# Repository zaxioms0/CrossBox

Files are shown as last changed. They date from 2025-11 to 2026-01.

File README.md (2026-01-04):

# CrossBox
A printer for the NYT mini crossword

Thanks for visiting! [People on Reddit](https://www.reddit.com/r/crossword/comments/1oy7tg7/i_made_a_box_to_print_the_nyt_mini/) 
seemed to think this was cool, so I'm putting it on Github if anyone
else wants to make it. ~~This currently *does* work without an NYT Games subscription. Hopefully it stays that way :]~~ 
In order to use the NYT mini, you need to provide an NYT-S token which is availible to anyone with an NYT Games subscription. 
The boxes also can print the [Puzzmo Mini](https://www.puzzmo.com/today/)
if you do not have an NYT Games subscription. If you are interested in building this project for yourself,
I highly recommend using the version for the ESP32 as well as v3 of the box. 

The current version is in the `esp32` directory and all development going forward will be for it. Due to the changes to the NYT API 
and the lack of development, the `esp8266` version does not work and also will not be updated.

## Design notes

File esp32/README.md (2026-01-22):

# Usage Instructions
## Startup
When the box is plugged in, it will try to connect to the internet. If it succeeds, it will blink 3 times quickly. If it fails,
it will open up a WiFi network for configuring settings. Sometimes it will connect to the internet, but fail to obtain the time.
I think this is due to NTP server rate limiting. If this happens it will print an error message before restarting and trying again.

## Main Usage
- Press and release button: print the selected mini crossword.
- Press and hold button for 5 seconds: open up WiFi network for configuration settings.

## WiFi Configuration
During WiFi Configuration, the button will blink slowly. If it is blinking, it means there is a WiFi network called
`CrossBox Setup` that you can connect to. Once connected, it should open a captive portal automatically on modern devices (like airplane WiFi), but it can
also be accessed through any browser at IP Address `192.168.4.1`. In this menu you can:
- Set the WiFi network and password
- Add/Change the NYT-S token (see section)
- Set a time for automatic printing
- Switch between the NYT Mini and Puzzmo Mini

Settings which are left empty will not be updated. The box will not return to it's normal state until the settings
are saved (or it loses and regains power).

### NYT-S Token
In order to use the NYT mini, you need to provide an NYT-S cookie. You can aquire it by inspecting element 
on the NYT Mini site, going to storage, then cookies. And there should be an NYT-S cookie which is a base-64 string.
Make sure you just provide the string without any quotes or "NYT-S" prepended to it.

# Assembly
## Parts Required 
- [ESP32](https://www.amazon.com/dp/B0D8T53CQ5?ref=ppx_yo2ov_dt_b_fed_asin_title).
- [Thermal Printer](https://www.amazon.com/dp/B09YGVPPWV).
- [Buck Converter](https://www.amazon.com/UCTRONICS-Converter-Transformer-Voltage-Regulator/dp/B07XXWQ49N).
- [Arcade Button](https://www.amazon.com/dp/B07XYV5NNP)
- Power Supply. I used 9v 3a. Anything more than 5v 3a should be sufficient.
- 6mm diameter x 1 mm width magnets (for box v3).
- Misc. Wires

## Wiring Directions
All you need is one power rail and one ground rail wired in a clear manner, positive out of the buck converter to one, 
ground of the buck converter to the other. The power wires of the printer are connected to these rails as well as the VIN
pin of the ESP32 to power and its ground to the ground rail. The wires that depend on specific pins are configured as follows:

- Printer TX to GPIO 25.
- Printer RX to GPIO 26.
- One button press terminal to GPIO 19.
- Other button press terminal to ground (ESP32 pin or rail).
- Button positive LED to GPIO 18.
- Button negative LED to GPIO 5.

If you are using the parts linked above, physical descriptions of the relevant wires/terminals are in [globals.h](src/globals.h).

## Software Directions
I used PlatformIO for all of the library handling. The only important note is you need to change the Baud rate to 9600
on line 38 of Adafruit_Thermal.cpp when it is downloaded.

The `ALI_EXPRESS` flag in `globals.h` should be set to `0` for the version of the printer I linked above.
This is used for a model which doesn't have as good defaults and has some settings that need to be set manually.

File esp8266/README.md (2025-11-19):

# Parts
Here is a list of parts I used (not including wires and stuff)

I included Amazon Links to the exact models of some of the parts that I used. You can probably get them
for cheaper on Ali Express or similar - I am fortunate to have a robotics club that stocks these for me :]

- 12v to 5v buck converter
- Breadboard
- 12v 3a power supply
- [58mm thermal printer](https://www.amazon.com/Maikrt-Embedded-Microcontroller-Secondary-Development/dp/B09YGVPPWV)
- [WEMOS D1 Mini](https://www.amazon.com/Hosyond-Wireless-Internet-Development-Compatible/dp/B09SPYY61L)

# Setup
## Software
I use PlatformIO to handle dependencies. The only thing in software that needs to be changed are your
wifi SSID and password, and ROOT CA certificate in `src/creds.h`.

The way it works is that a button resets the microcontroller and it reconnects to the internet.
To be honest this is not a great design because it takes a long time to connect to the internet every time.
I did this because I have no idea how the JSON parser is allocating memory and I'm worried about using too much
if it leaks or something. I want to improve this in the future.

## Hardware
Besides 3D printing the models, the wiring is fairly straightforward. 
Here are the connections neccesary:
- Buck Converter -> Breadboard: positive goes to positive, negative to negative
- Breadboard Power Rails -> D1 Mini: Positive to 5v, negative to ground
- Printer Power -> Power Rails: positive to positive, negative to negative
- Printer TTL -> Breadboard: ground to ground, RX to GPIO 16, TX to GPIO 14
- Big Button -> Breadboard: positive to reset, negative to ground

Your power supply should supply 12v into the buck converter and at least 3 amps. 
If you have a power supply with 5 volts and 3 (or more) amps, the buck converter can be skipped.

# Disclaimer
I am fairly new to this whole electronics thing, lots of things can (and probably will) be improved.
In particular, I want to handle JSON parsing without a library for space reasons. 
Also, the box design right now is too tight, I plan to change it to use magnets for the connection in v3.

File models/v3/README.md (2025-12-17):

# Materials
Version 3 of the box requires 8 magnets with a diameter of 6mm and a depth of 1mm.

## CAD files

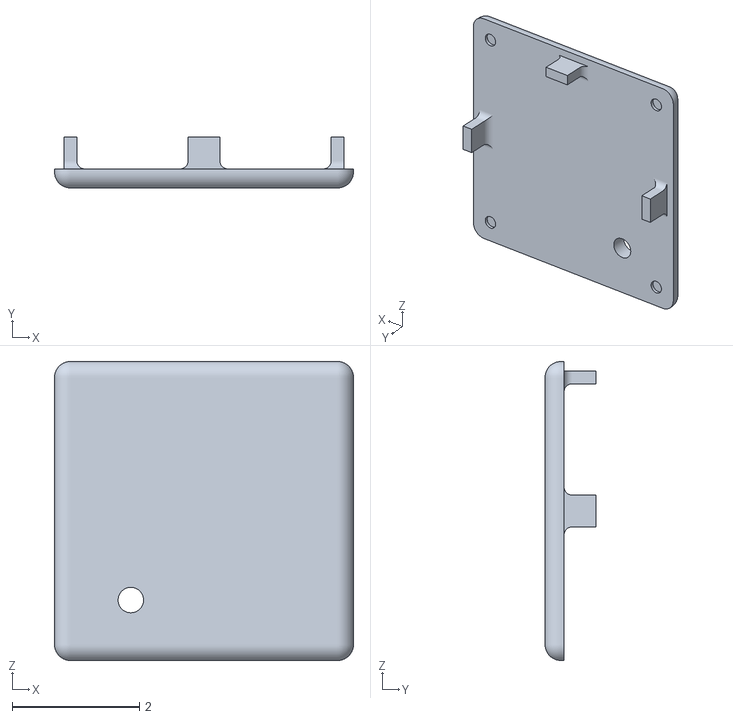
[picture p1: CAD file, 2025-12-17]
models/v3/back.stl
4.70 x 0.8 x 4.70

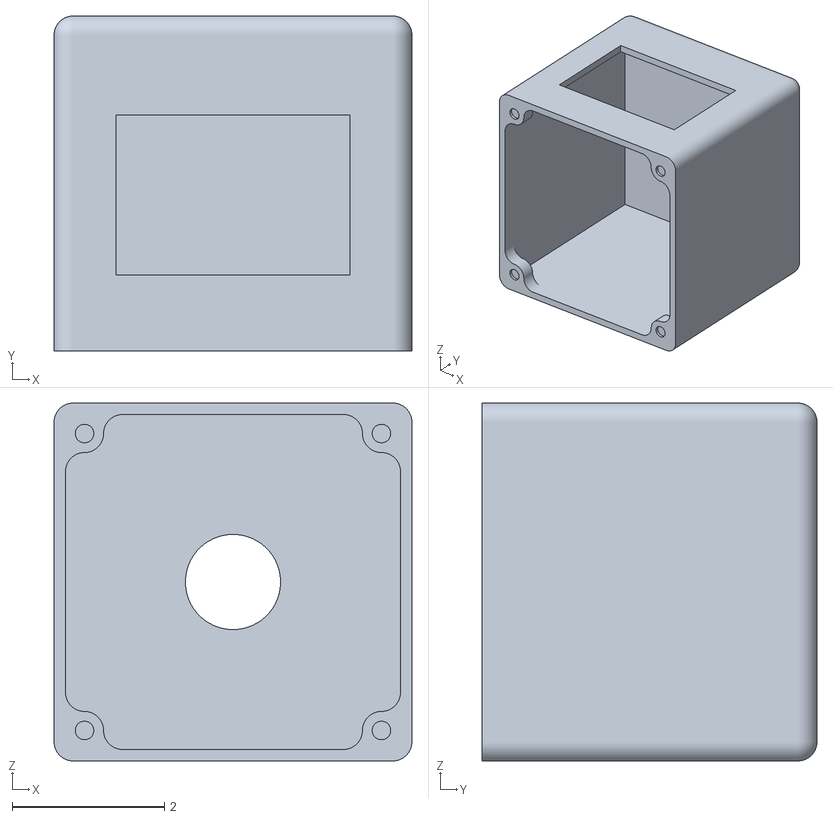
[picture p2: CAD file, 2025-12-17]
models/v3/box.stl
4.70 x 4.40 x 4.70

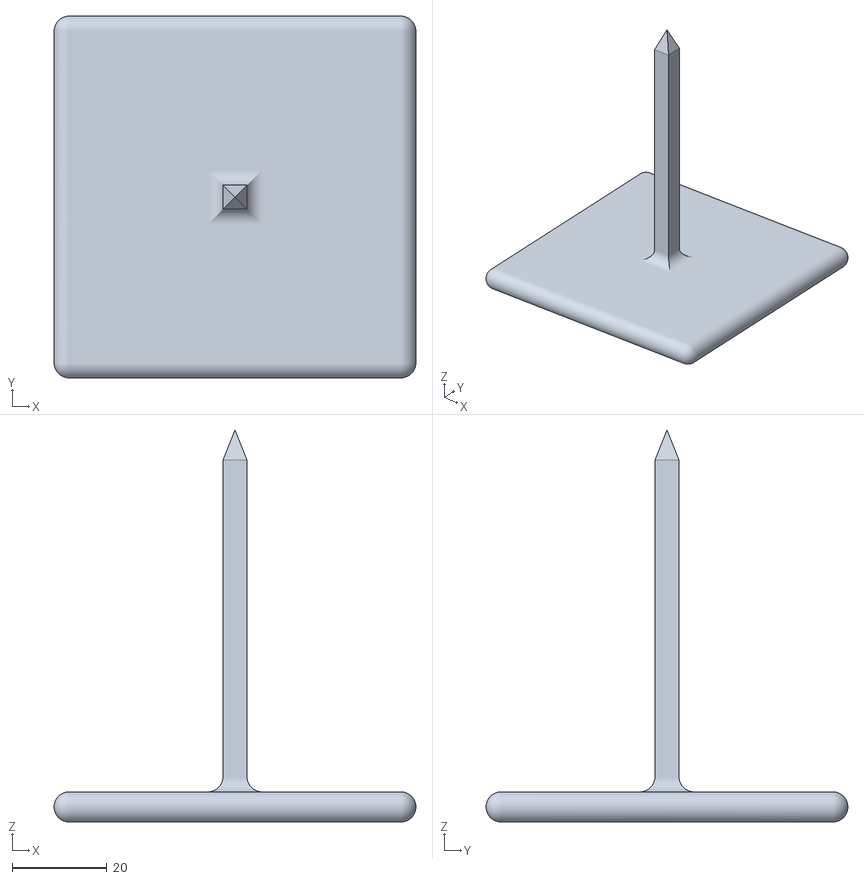
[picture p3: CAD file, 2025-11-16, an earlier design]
models/v2/spike.stl
76.2 x 76.2 x 82.5

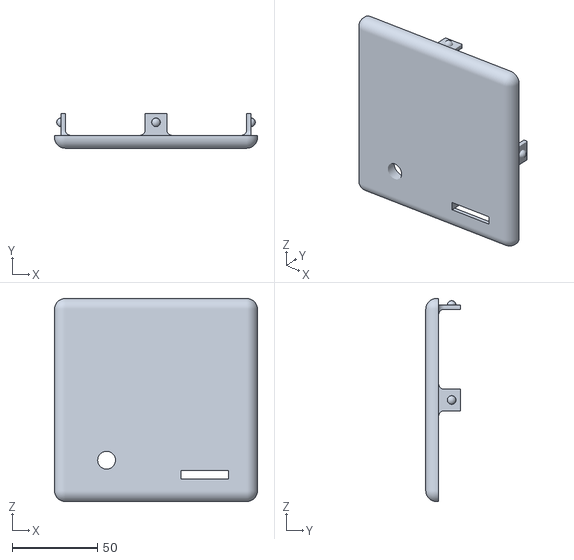
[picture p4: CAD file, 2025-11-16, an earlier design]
models/v2/back.stl
119.4 x 20.3 x 119.4

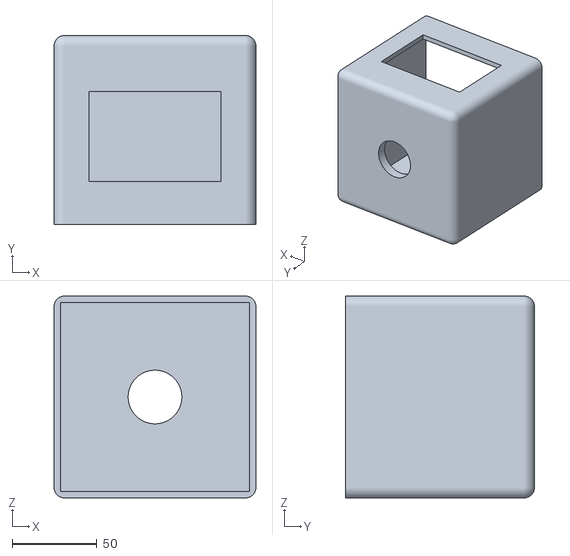
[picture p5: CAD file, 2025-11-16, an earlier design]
models/v2/box.stl
119.4 x 111.8 x 119.4

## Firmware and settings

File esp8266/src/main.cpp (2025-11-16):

#include "SoftwareSerial.h"
#include <Adafruit_Thermal.h>
#include <Arduino.h>
#include <ArduinoJson.h>
#include <ESP8266HTTPClient.h>
#include <ESP8266WiFi.h>
#include <WiFiClientSecure.h>
#include <creds.h>
#include <nums.h>
#include <time.h>
#include <vector>

// RX, TX
SoftwareSerial printer_serial(14, 16);
Adafruit_Thermal printer(&printer_serial);
int board_px = 384;
const int scratch_size = 4400;
char scratch[scratch_size] = "{\"cells\":";

struct GridData {
    int height;
    int width;
    std::vector<String> authors;
    // ((x, y), data)
    std::vector<std::pair<std::pair<int, int>, int>> square_data;
    std::vector<std::pair<int, String>> across_clues;
    std::vector<std::pair<int, String>> down_clues;
};

void printGridData(GridData d) {
    Serial.printf("Height: %d\n", d.height);
    Serial.printf("Width: %d\n", d.width);
    Serial.print("Author(s): ");
    for (size_t i = 0; i < d.authors.size(); i++) {
        Serial.print(d.authors[i].c_str());
        if (i < d.authors.size() - 1)
            Serial.print(", ");
    }
    Serial.println();
    Serial.print("Data: ");
    for (auto p : d.square_data) {
        Serial.printf("<(%d, %d) : %d> ", p.first.first, p.first.second,
                      p.second);
    }
    Serial.println();
    Serial.println("Across:");
    for (auto p : d.across_clues) {
        Serial.printf("%d: %s\n", p.first, p.second.c_str());
    }
    Serial.println();
    Serial.println("Down:");
    for (auto p : d.down_clues) {
        Serial.printf("%d: %s\n", p.first, p.second.c_str());
    }
}

void getDateString(char *buff, bool pp) {
    struct tm timeinfo;
    if (!getLocalTime(&timeinfo)) {
        Serial.println("Failed to obtain time");
        exit(1);
    }
    if (pp)
        sprintf(buff, "%d/%d/%d", 1 + timeinfo.tm_mon, timeinfo.tm_mday,
                1900 + timeinfo.tm_year);
    else
        sprintf(buff, "%d-%d-%d", 1900 + timeinfo.tm_year, 1 + timeinfo.tm_mon,
                timeinfo.tm_mday);
}

// returns index of null terminator in buff
int readStreamUntil(WiFiClient *stream, const char *match, int match_len,
                    char *buffer, int buffer_len) {
    int i = 0;
    int idx = 0;
    while ((stream->connected() || stream->available()) && i < match_len &&
           (!buffer || (idx < buffer_len))) {
        if (stream->available()) {
            char c = stream->read();
            if (c == match[i]) {
                i += 1;
            } else {
                i = 0;
            }
            if (buffer != NULL) {
                buffer[idx] = c;
            }
            idx += 1;
        } else {
            yield();
        }
    }
    if (buffer != NULL)
        buffer[idx] = 0;
    return idx;
}

GridData getGridData() {
    char url[128];
    char date[64];
    WiFiClientSecure client;
    HTTPClient http;
    getDateString(date, false);
    sprintf(url,
            "https://www.nytimes.com/svc/crosswords/v6/puzzle/mini/%s.json",
            date);
    Serial.println(url);

    http.setFollowRedirects(HTTPC_STRICT_FOLLOW_REDIRECTS);
    client.setTrustAnchors(new X509List(root_ca));
    http.begin(client, url);

    delay(1000);
    int httpResponseCode = http.GET();
    if (httpResponseCode == 403) {
        // try again with tomorrow's date
        configTime((24 - 4) * 60 * 60, 0, "time.google.com");
        getDateString(date, false);
        sprintf(url,
                "https://www.nytimes.com/svc/crosswords/v6/puzzle/mini/%s.json",
                date);
        http.begin(client, url);
        delay(1000);
        httpResponseCode = http.GET();
    }

    if (httpResponseCode != 200) {
        Serial.printf("Failed to get NYT data. HTTP response: %d\n",
                      httpResponseCode);
        exit(1);
    }

    auto s = http.getStreamPtr();
    JsonDocument doc;
    bool succeeded = false;
    {
        for (int i = 0; i < 3; i++) {
            const char start_target[9] = "\"cells\":";
            const char end_target[4] = "SVG";

            readStreamUntil(s, start_target, 8, NULL, 0);
            int buf_len =
                readStreamUntil(s, end_target, 3, scratch + 9, scratch_size);
            scratch[9 + buf_len - 5] = '}';
            scratch[9 + buf_len - 4] = 0;
            DeserializationError error = deserializeJson(doc, scratch);
            if (error) {
                Serial.println("JSON parsing failed: ");
                Serial.println(error.c_str());
                Serial.print(scratch);
                http.GET();
                s = http.getStreamPtr();
            } else {
                succeeded = true;
                break;
            }
        }
    }
    if (!succeeded) {
        Serial.println("Didn't work. Sorry :(");
        exit(1);
    }
    // serializeJsonPretty(doc, Serial);
    GridData data;
    data.height = doc["dimensions"]["height"].as<int>();
    data.width = doc["dimensions"]["width"].as<int>();
    data.square_data = {};
    data.authors = {};
    data.across_clues = {};
    data.down_clues = {};
    for (int j = 0; j < data.height; j++) {
        for (int i = 0; i < data.width; i++) {
            int idx = i + data.width * j;
            if (doc["cells"][idx] &&
                doc["cells"][idx].as<JsonObject>().size() == 0) {
                data.square_data.push_back({{i, j}, 0});
            } else if (doc["cells"][idx]["label"]) {
                int label =
                    atoi(doc["cells"][idx]["label"].as<String>().c_str());
                data.square_data.push_back({{i, j}, label});
            }
        }
    }
    for (auto clue : doc["clues"].as<JsonArray>()) {
        String direction = clue["direction"].as<String>();
        int label = atoi(clue["label"].as<String>().c_str());
        String text = clue["text"][0]["plain"].as<String>();
        if (strcmp(direction.c_str(), "Across") == 0) {
            data.across_clues.push_back({label, text});
        } else {
            data.down_clues.push_back({label, text});
        }
    }
    doc.clear();
    const char start_target[16] = "\"constructors\":";
    const char end_target[12] = "\"copyright\"";
    readStreamUntil(s, start_target, 15, NULL, 0);
    strcpy(scratch, "{\"constructors\":");
    int buflen = readStreamUntil(s, end_target, 11, scratch + 16, scratch_size);
    scratch[16 + buflen - 12] = '}';
    scratch[16 + buflen - 11] = 0;
    Serial.printf("%d, %s\n", buflen, scratch);
    Serial.flush();
    DeserializationError error = deserializeJson(doc, scratch);
    if (error) {
        Serial.println("JSON parsing constructors failed: ");
        Serial.println(error.c_str());
        exit(1);
    }
    for (auto author : doc["constructors"].as<JsonArray>()) {
        String a = author.as<String>();
        data.authors.push_back(a);
    }

    printGridData(data);
    digitalWrite(2, HIGH);

    return data;
}

void writeScratchBit(int i) {
    int b = i / 8;
    int offset = 7 - (i % 8);
    scratch[b] |= ((char)1) << offset;
}

void writeOutline(int square_dim, int width) {
    for (int x = 0; x < width; x++) {
        for (int i = 0; i < square_dim; i++) {
            // top
            writeScratchBit(x * square_dim + i);
            writeScratchBit(x * square_dim + board_px + i);
            // left
            writeScratchBit(x * square_dim + (board_px * i));
            writeScratchBit(x * (square_dim) + (board_px * i) + 1);
            // bottom
            writeScratchBit(x * square_dim + (board_px * (square_dim - 2)) + i);
            writeScratchBit(x * square_dim + (board_px * (square_dim - 1)) + i);
        }
    }
    // right
    for (int i = 0; i < square_dim; i++) {
        writeScratchBit(i * board_px + (board_px - 1));
        writeScratchBit(i * board_px + (board_px - 2));
    }
}

void writeSquare(int col, int square_dim, int data) {
    // fill in
    if (data == 0) {
        for (int i = 0; i < square_dim; i++) {
            for (int j = 0; j < square_dim; j++) {
                int idx = (col * square_dim) + i + (board_px * j);
                writeScratchBit(idx);
            }
        }
        return;
    }
    int offset = 3;
    // one digit
    if (data <= 9) {
        for (int j = 0; j < 16; j++) {
            for (int i = 0; i < 16; i++) {
                if (!read_num_bit(data, i, j)) {
                    int idx = col * square_dim + (i + offset) +
                              ((j + offset) * board_px);
                    writeScratchBit(idx);
                }
            }
        }
        return;
    }
    // two digit
    int d1 = data / 10;
    int d2 = data % 10;
    for (int j = 0; j < 16; j++) {
        for (int i = 0; i < 16; i++) {
            if (!read_num_bit(d1, i, j)) {
                int idx =
                    col * square_dim + (i + offset) + ((j + offset) * board_px);
                writeScratchBit(idx);
            }
            if (!read_num_bit(d2, i, j)) {
                int idx2 = col * square_dim + (i + 8 + offset) +
                           ((j + offset) * board_px);
                writeScratchBit(idx2);
            }
        }
    }
}

void writeBoardRow(int row, GridData grid_data) {
    int square_dim = board_px / grid_data.width;
    memset(scratch, 0, scratch_size);
    writeOutline(square_dim, grid_data.width);
    for (auto p : grid_data.square_data) {
        if (p.first.second == row) {
            writeSquare(p.first.first, square_dim, p.second);
        }
    }
}

void printGrid(GridData grid_data) {
    int tmp = board_px;
    for (int i = 0; i < tmp / 8; i++) {
        if (board_px % grid_data.width == 0) {
            break;
        }
        board_px -= 8;
    }
    // Serial.printf("Board px: %d\n", board_px);
    for (int i = 0; i < grid_data.height; i++) {
        writeBoardRow(i, grid_data);
        // Serial.println(board_px / grid_data.width);
        // for (int j = 0; j < (board_px * board_px / grid_data.width / 8); j++)
        // {
        //     Serial.printf("0x%02x ", scratch[j]);
        // }
        printer.printBitmap(board_px, board_px / grid_data.width,
                            (unsigned char *)scratch, true);
    }
}

void printHeader(GridData data) {
    printer.justify('C');
    printer.boldOn();
    printer.doubleHeightOn();
    printer.doubleWidthOn();
    printer.println(F("NYT MINI"));
    printer.boldOff();
    printer.doubleHeightOff();
    printer.doubleWidthOff();
    char date[64];
    getDateString(date, true);
    printer.println(date);
    if (data.authors.size() == 1) {
        printer.print("Author: ");
    } else {
        printer.print("Authors: ");
    }
    for (size_t i = 0; i < data.authors.size(); i++) {
        printer.print(data.authors[i].c_str());
        if (i < data.authors.size() - 1)
            Serial.print(", ");
    }
    printer.println();
}

void printClues(GridData data) {
    printer.justify('L');
    printer.boldOn();
    printer.doubleHeightOn();
    printer.doubleWidthOn();
    printer.println("Across:");
    printer.boldOff();
    printer.doubleHeightOff();
    printer.doubleWidthOff();
    for (auto clue : data.across_clues) {
        printer.printf("%d) %s\n", clue.first, clue.second.c_str());
    }
    printer.println();
    printer.doubleHeightOn();
    printer.doubleWidthOn();
    printer.println("Down:");
    printer.boldOff();
    printer.doubleHeightOff();
    printer.doubleWidthOff();
    for (auto clue : data.down_clues) {
        printer.printf("%d) %s\n", clue.first, clue.second.c_str());
    }
    printer.println();
    printer.println();
    printer.println();

}

void setup() {
    pinMode(2, OUTPUT);
    digitalWrite(2, LOW);
    Serial.begin(115200);
    printer_serial.begin(9600);

    delay(10);
    Serial.println('\n');

    WiFi.begin(ssid, password);
    Serial.print("Connecting to ");
    Serial.print(ssid);
    Serial.println(" ...");

    int i = 0;
    while (WiFi.status() != WL_CONNECTED) { // Wait for the Wi-Fi to connect
        delay(1000);
        Serial.print(++i);
        Serial.print(' ');
    }

    Serial.println('\n');
    Serial.println("Connection established!");
    configTime(-4 * 60 * 60, 0, "time.google.com");

    GridData data = getGridData();
    printer.begin();
    printHeader(data);
    printGrid(data);
    printClues(data);
}

void loop() {}

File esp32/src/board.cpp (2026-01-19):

#include "board.h"
#include "globals.h"
#include "util.h"
#include <Adafruit_Thermal.h>
#include <Arduino.h>
#include <optional>
#include <time.h>
#include <vector>

const unsigned char nums[10][32] = {
    {0xff, 0xff, 0xfc, 0x7f, 0xf9, 0x3f, 0xf3, 0x9f, 0xf7, 0x9f, 0xf7,
     0xdf, 0xf7, 0xdf, 0xf7, 0xdf, 0xf7, 0xdf, 0xf7, 0x9f, 0xf3, 0x9f,
     0xf9, 0x3f, 0xfc, 0x7f, 0xff, 0xff, 0xff, 0xff, 0xff, 0xff},
    {0xff, 0xff, 0xff, 0x7f, 0xfe, 0x7f, 0xfc, 0x7f, 0xfb, 0x7f, 0xff,
     0x7f, 0xff, 0x7f, 0xff, 0x7f, 0xff, 0x7f, 0xff, 0x7f, 0xff, 0x7f,
     0xff, 0x7f, 0xff, 0x7f, 0xff, 0xff, 0xff, 0xff, 0xff, 0xff},
    {0xff, 0xff, 0xfc, 0x7f, 0xf3, 0x3f, 0xf7, 0x9f, 0xf7, 0xdf, 0xff,
     0x9f, 0xff, 0xbf, 0xff, 0x3f, 0xfe, 0x7f, 0xf9, 0xff, 0xfb, 0xff,
     0xf3, 0xff, 0xf0, 0x1f, 0xff, 0xff, 0xff, 0xff, 0xff, 0xff},
    {0xff, 0xff, 0xfc, 0x7f, 0xf3, 0x3f, 0xf7, 0x9f, 0xff, 0x9f, 0xff,
     0x3f, 0xfe, 0x3f, 0xff, 0x9f, 0xff, 0x9f, 0xff, 0xdf, 0xf7, 0x9f,
     0xf3, 0x3f, 0xf8, 0x7f, 0xff, 0xff, 0xff, 0xff, 0xff, 0xff},
    {0xff, 0xff, 0xff, 0x3f, 0xfe, 0x3f, 0xfe, 0x3f, 0xfd, 0x3f, 0xf9,
     0x3f, 0xfb, 0x3f, 0xf3, 0x3f, 0xe7, 0x3f, 0xe0, 0x1f, 0xff, 0x3f,
     0xff, 0x3f, 0xff, 0x3f, 0xff, 0xff, 0xff, 0xff, 0xff, 0xff},
    {0xff, 0xff, 0xf8, 0x1f, 0xfb, 0xff, 0xfb, 0xff, 0xf3, 0xff, 0xf0,
     0x3f, 0xf3, 0x1f, 0xff, 0x9f, 0xff, 0xdf, 0xff, 0xdf, 0xf7, 0x9f,
     0xf3, 0x3f, 0xf8, 0x7f, 0xff, 0xff, 0xff, 0xff, 0xff, 0xff},
    {0xff, 0xff, 0xfc, 0x7f, 0xf9, 0xbf, 0xf3, 0x9f, 0xf7, 0xff, 0xf4,
     0x3f, 0xf1, 0x3f, 0xf3, 0x9f, 0xf7, 0xdf, 0xf7, 0xdf, 0xf3, 0x9f,
     0xf9, 0x3f, 0xfc, 0x7f, 0xff, 0xff, 0xff, 0xff, 0xff, 0xff},
    {0xff, 0xff, 0xf0, 0x1f, 0xff, 0x9f, 0xff, 0xbf, 0xff, 0x3f, 0xfe,
     0x7f, 0xfe, 0x7f, 0xfe, 0xff, 0xfc, 0xff, 0xfd, 0xff, 0xfd, 0xff,
     0xfd, 0xff, 0xf9, 0xff, 0xff, 0xff, 0xff, 0xff, 0xff, 0xff},
    {0xff, 0xff, 0xfc, 0x7f, 0xf9, 0x3f, 0xf3, 0x9f, 0xf3, 0x9f, 0xfb,
     0xbf, 0xf8, 0x3f, 0xf3, 0x3f, 0xf7, 0x9f, 0xf7, 0xdf, 0xf7, 0x9f,
     0xf3, 0x1f, 0xf8, 0x7f, 0xff, 0xff, 0xff, 0xff, 0xff, 0xff},
    {0xff, 0xff, 0xf8, 0x7f, 0xf3, 0x3f, 0xf7, 0x9f, 0xf7, 0xdf, 0xf7,
     0x9f, 0xf3, 0x9f, 0xf8, 0x5f, 0xff, 0xdf, 0xff, 0x9f, 0xf7, 0x9f,
     0xf3, 0x3f, 0xf8, 0x7f, 0xff, 0xff, 0xff, 0xff, 0xff, 0xff},
};

bool readNumBit(int num, int i, int j) {
    int idx = 16 * j + i;
    int b = idx / 8;
    char offset = 1 << (7 - (idx % 8));
    return (nums[num][b] & offset) ? 1 : 0;
}

bool validateAscii(String &s) {
    for (unsigned char c : s) {
        if (c > 127)
            return false;
    }
    return true;
}

void printGridDataSerial(Grid d) {
    Serial.printf("Height: %d\n", d.height);
    Serial.printf("Width: %d\n", d.width);
    Serial.print("Constructors(s): ");
    for (size_t i = 0; i < d.authors.size(); i++) {
        Serial.print(d.authors[i].c_str());
        if (i < d.authors.size() - 1)
            Serial.print(", ");
    }
    Serial.println();
    Serial.print("Data: ");
    for (auto p : d.square_data) {
        Serial.printf("<(%d, %d) : %d> ", p.row, p.col, p.data);
    }
    Serial.println();
    Serial.println("Across:");
    for (auto p : d.across_clues) {
        Serial.printf("%d: %s\n", p.num, p.data.c_str());
    }
    Serial.println();
    Serial.println("Down:");
    for (auto p : d.down_clues) {
        Serial.printf("%d: %s\n", p.num, p.data.c_str());
    }
}

void writeScratchBit(int idx) {
    int b = idx / 8;
    int offset = 7 - (idx % 8);
    scratch[b] |= ((char)1) << offset;
}

// write to "logical" position in bitmap
// e.g. assuming an n x n bitmap is truly
// n x n, not worrying about row allignment
// or centering
void writeScratchBitLogical(int i) {
    // centering
    int idx = i + (MAX_BOARD - board_px) * (i / board_px); // byte align in bitmap
    writeScratchBit(idx);
}

void writeOutline(int square_dim, int width, bool close) {
    for (int x = 0; x < width; x++) {
        for (int i = 0; i < square_dim; i++) {
            // top
            writeScratchBitLogical(x * square_dim + i);
            // writeScratchBitLogical(x * square_dim + board_px + i);
            //  left
            writeScratchBitLogical(x * square_dim + (board_px * i));
            // writeScratchBitLogical(x * square_dim + (board_px * i) + 1);
            //  bottom
            if (close)
                writeScratchBitLogical(x * square_dim + (board_px * (square_dim - 1)) +
                                       i);
            // writeScratchBitLogical(x * square_dim + (board_px * (square_dim - 2)) +
            // i);
        }
    }
    // right
    for (int i = 0; i < square_dim; i++) {
        writeScratchBitLogical(i * board_px + (board_px - 1));
        // writeScratchBitLogical(i * board_px + (board_px - 2));
    }
}
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

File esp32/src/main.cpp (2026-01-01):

#include "globals.h"
#include "nyt.h"
#include "puzzmo.h"
#include "util.h"
#include "wifi_setup.h"
#include <Arduino.h>
#include <WiFi.h>

void setup() {
    pinMode(ONBOARD_LED, OUTPUT);
    pinMode(BUTT_LED, OUTPUT);
    pinMode(BUTT_LED_OUT, OUTPUT);
    pinMode(BUTT, INPUT_PULLUP);

    digitalWrite(BUTT_LED_OUT, LOW);
    digitalWrite(ONBOARD_LED, LOW);

    Serial.begin(115200);
    Serial1.begin(9600, SERIAL_8N1, RX, TX);
    printer.begin();

    delay(10);

    wm.addParameter(&nyts_param);
    wm.addParameter(&print_time_param);
    wm.addParameter(&crosstype_param);
    wm.setEnableConfigPortal(false);
    if (!wm.autoConnect()) {
        wm.setEnableConfigPortal(true);
        WifiSetup();
    }
    wm.setEnableConfigPortal(true);
    Serial.println('\n');
    Serial.println("Connection established!");
    configTime(0, 0, "time.google.com", "pool.ntp.org");
    setenv("TZ", "EST5EDT,M3.2.0/2,M11.1.0/2", 1);
    tzset();

    prefs.begin("config", false);
    print_hr = prefs.getInt("print_time", -1);
    primary_cross = (CrossType)prefs.getInt("cross_type", NYT);
    strcpy(nyts, prefs.getString("nyts", "").c_str());
    strcpy(ssid, prefs.getString("ssid", "").c_str());
    strcpy(wifi_pass, prefs.getString("wifi_pass", "").c_str());
    Serial.printf("Setup to print at %d\n", print_hr);
    prefs.end();

    WiFi.setSleep(false);
    if (!ensureInternet()) {
        char msg[256];
        sprintf(msg,
                "Was not connected to WiFi network: %s and "
                "password: %s at end of startup sequence. Restarting.",
                ssid, wifi_pass);
        printDebug(msg);
        ESP.restart();
    }
    struct tm timeinfo;
    if (!getLocalTime(&timeinfo)) {
        Serial.println("SETUP FAILED");
        char msg[] = "Could not retrieve time at end of startup sequence despite being "
                     "connected to WiFi. Restarting.";
        printDebug(msg);
        ESP.restart();
    }
    Serial.println("Setup Complete");
    xTaskCreate(threadBlink, "blink", 1024, (void *)3, 1, NULL);
}

void printPrimaryCrossword() {
    switch (primary_cross) {
    case NYT: {
        if (strlen(nyts) <= 5) { // "" or "NYT-S"
            char msg[] = "NYT-S Cookie not set";
            printDebug(msg);
            break;
        }
        getAndPrintNYTCrossword();
        break;
    }
    case Puzzmo: {
        getAndPrintPuzzmoCrossword();
        break;
    }
    default: {
        char msg[] = "Primary crossword set improperly.";
        printDebug(msg);
    }
    }
}

void loop() {
    struct tm timeinfo;
    if (getLocalTime(&timeinfo)) {
        int hour = timeinfo.tm_hour;
        int minute = timeinfo.tm_min;
        if (hour == print_hr && !print_today) {
            if (!ensureInternet()) {
                char msg[128];
                sprintf(msg,
                        "Tried to print at %d:%02d, but failed to connect to the "
                        "internet.\n",
                        hour, minute);
                printDebug(msg);
            } else {
                TaskHandle_t handle;
                xTaskCreate(threadBlink, "blink", 1024, (void *)-1, 1, &handle);
                printPrimaryCrossword();
                vTaskDelete(handle);
                digitalWrite(BUTT_LED, LOW);
            }
            print_today = true;
        } else if (hour == 0 && minute == 1) {
            print_today = false;
        }
    }

    int cur_button = digitalRead(BUTT);

    // press
    if (cur_button == LOW && !pressed) {
        press_time = millis();
        pressed = true;
    }

    // unpress
    if (pressed && cur_button == HIGH) {
        delay(20);
        if (digitalRead(BUTT) != HIGH)
            return;

        if (!ensureInternet() || !getLocalTime(&timeinfo)) {
            char msg[256];
            sprintf(msg,
                    "Tried to print, but was not connected to WiFi network: %s and "
                    "password: %s or could not get time. Please try again.",
                    ssid, wifi_pass);
            printDebug(msg);
        } else {
            Serial.println("Printing Start");
            TaskHandle_t handle;
            xTaskCreate(threadBlink, "blink", 1024, (void *)-1, 1, &handle);
            printPrimaryCrossword();
            vTaskDelete(handle);
            digitalWrite(BUTT_LED, LOW);
        }
        pressed = false;
        Serial.println(esp_get_free_heap_size());
    }

    // hold
    if (pressed && millis() - press_time > 5000) {
        WifiSetup();
        pressed = false;
    }
}

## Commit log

2025-12-17 add box v3
    [back.stl, box.stl]
2025-12-19 some small fixes. Also removed always on light to blink while printing
    [board.cpp, globals.h, main.cpp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]
2025-12-23 add blink to timed print
2025-12-23 print debug fix
2026-01-19 alex bug fix and support ali express printers
    [board.cpp, globals.h, puzzmo.cpp]
